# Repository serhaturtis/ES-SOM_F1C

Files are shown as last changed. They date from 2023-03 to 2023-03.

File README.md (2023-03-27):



<br />
<div align="center">
  <a href="https://github.com/serhaturtis/SOM-F1C">
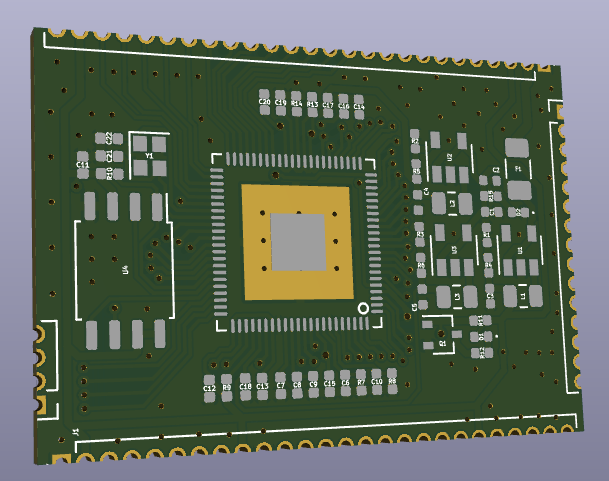
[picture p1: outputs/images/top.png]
    
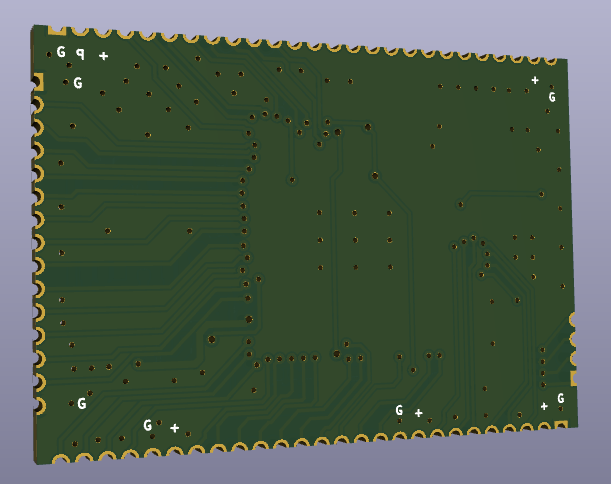
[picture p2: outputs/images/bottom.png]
    
  </a>

<h3 align="center">SOM-F1C</h3>

  <p align="center">
    A System-on-Module With Allwinner F1C Processor 
  </p>
</div>

<!-- WHAT -->
## What?

This is a linux capable system-on-module board made with Allwinner F1C processor. It can hold SPI flash memory (like 16MB NOR or 128MB NAND) on board. 

## Why?

Because I wanted to.

## How?

Headers are placed to the egdes so that manufacturer can recognize it for edge plating.

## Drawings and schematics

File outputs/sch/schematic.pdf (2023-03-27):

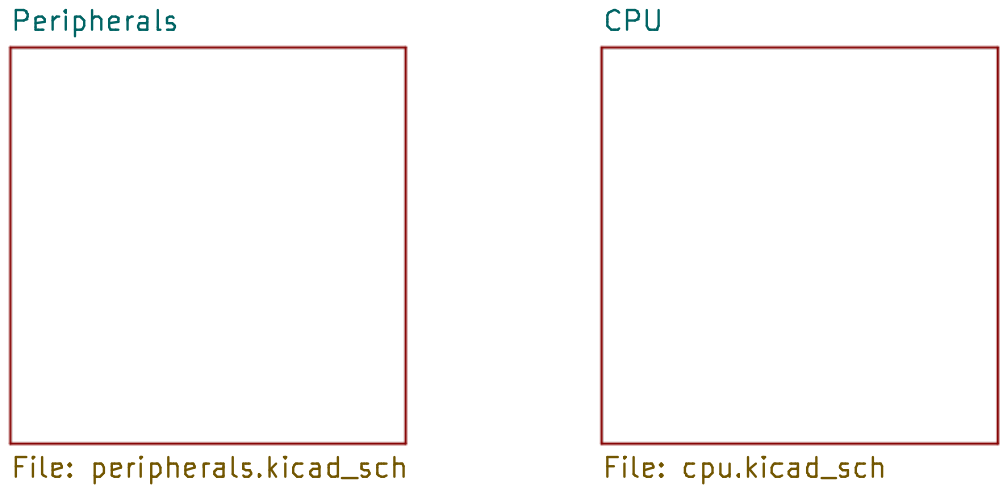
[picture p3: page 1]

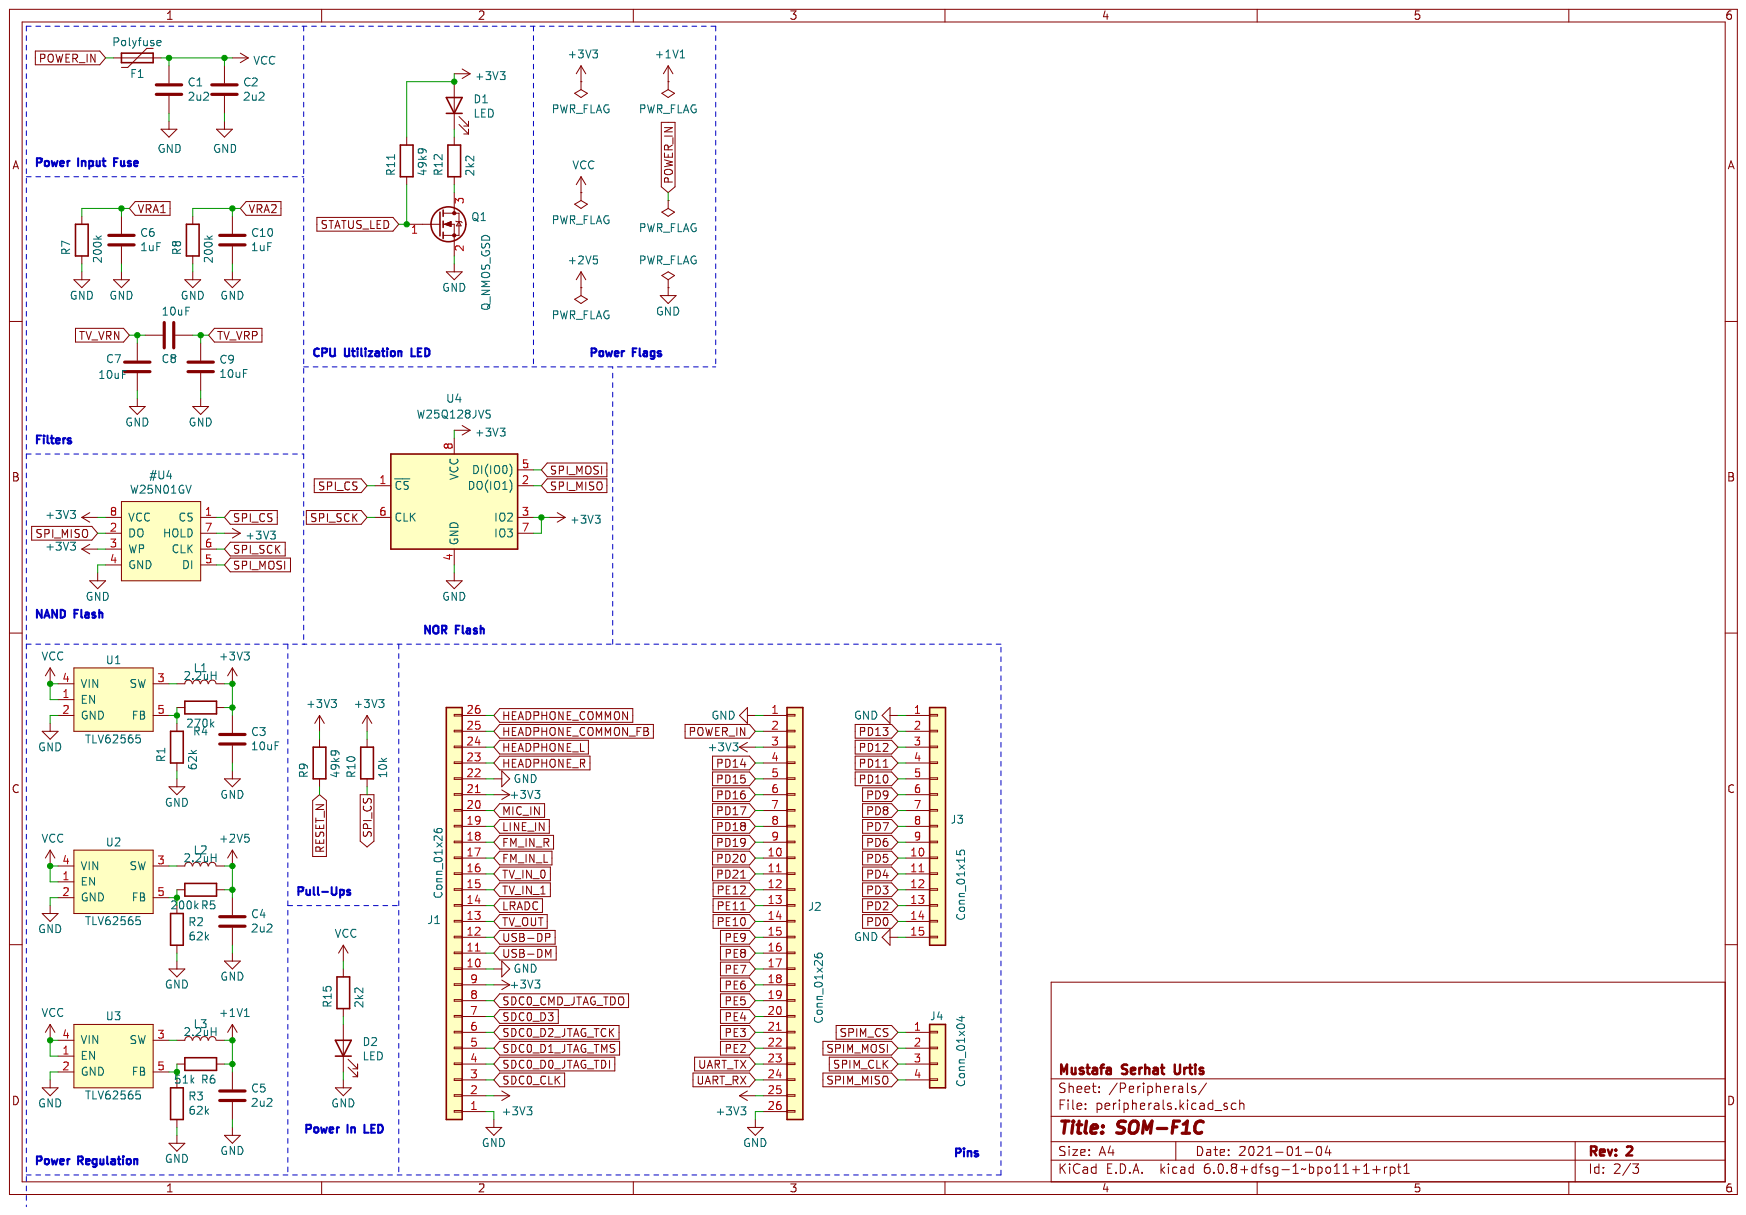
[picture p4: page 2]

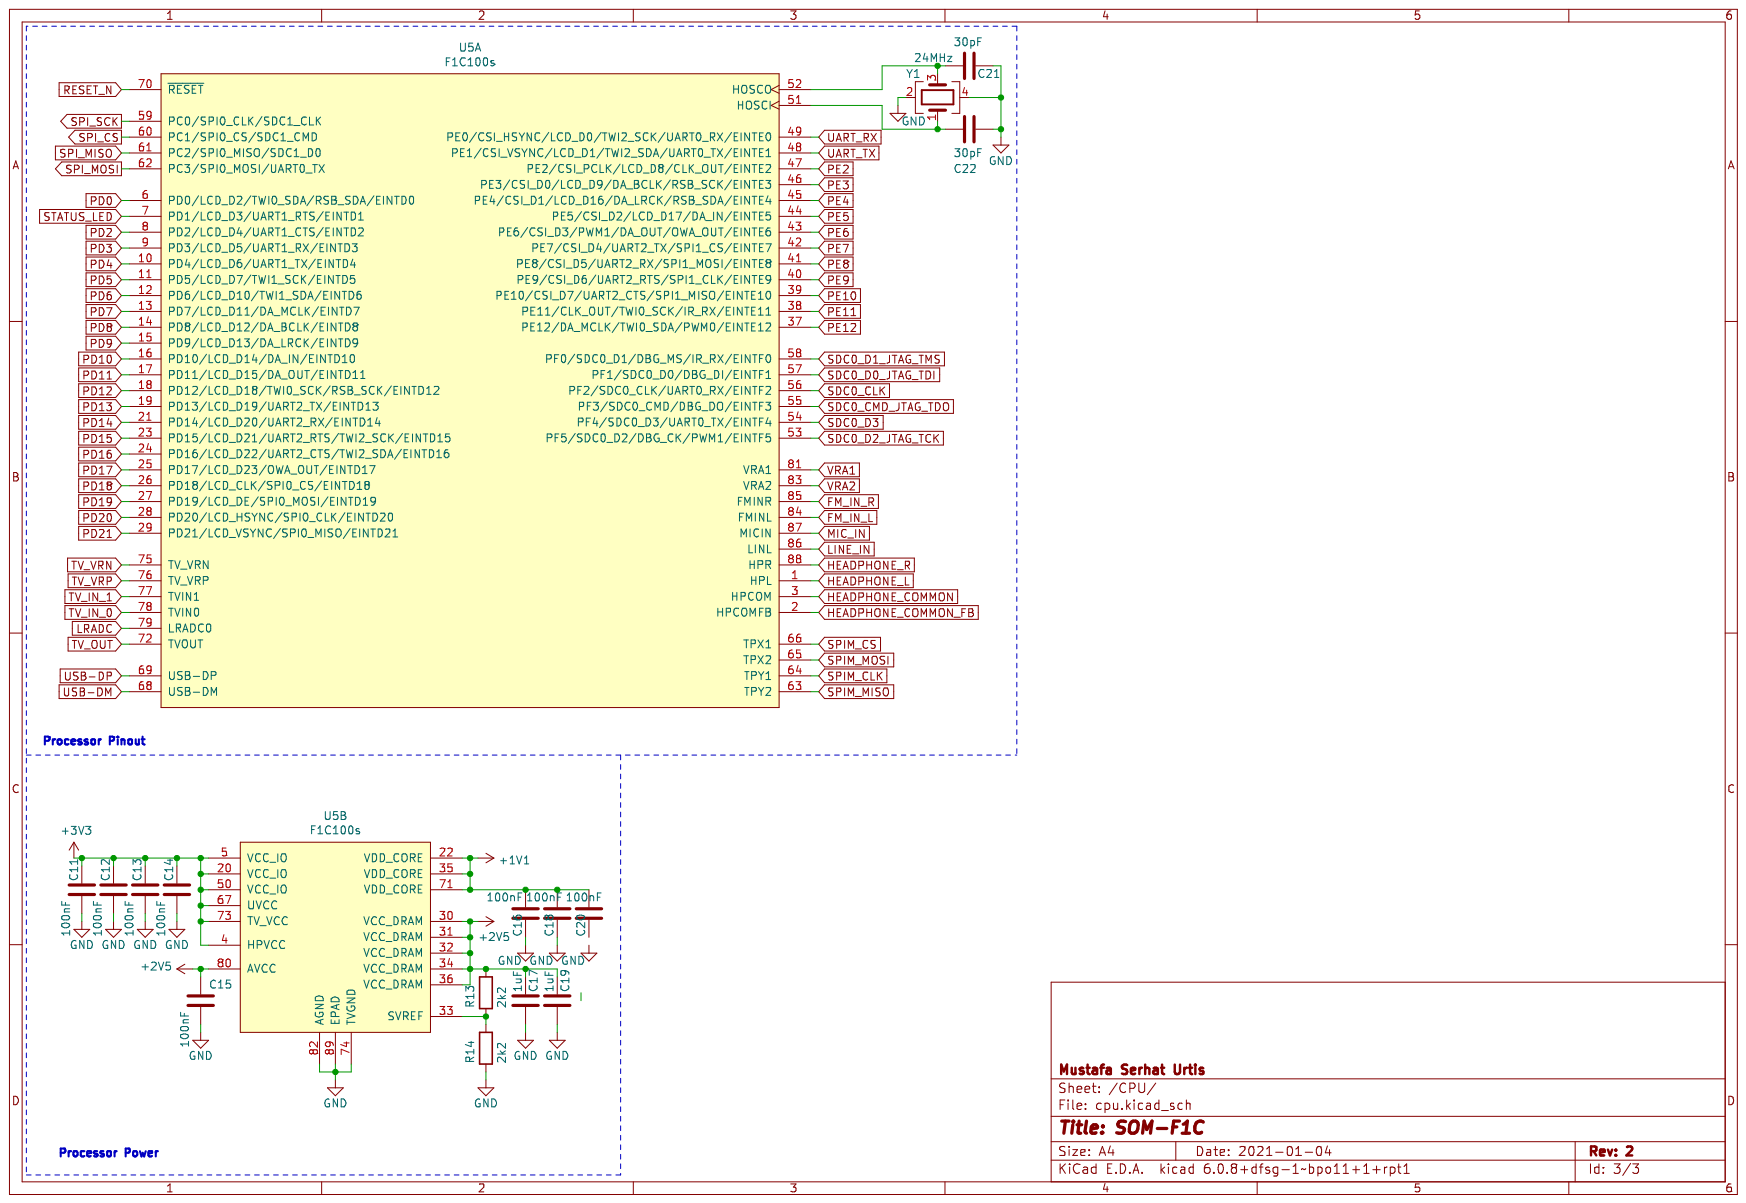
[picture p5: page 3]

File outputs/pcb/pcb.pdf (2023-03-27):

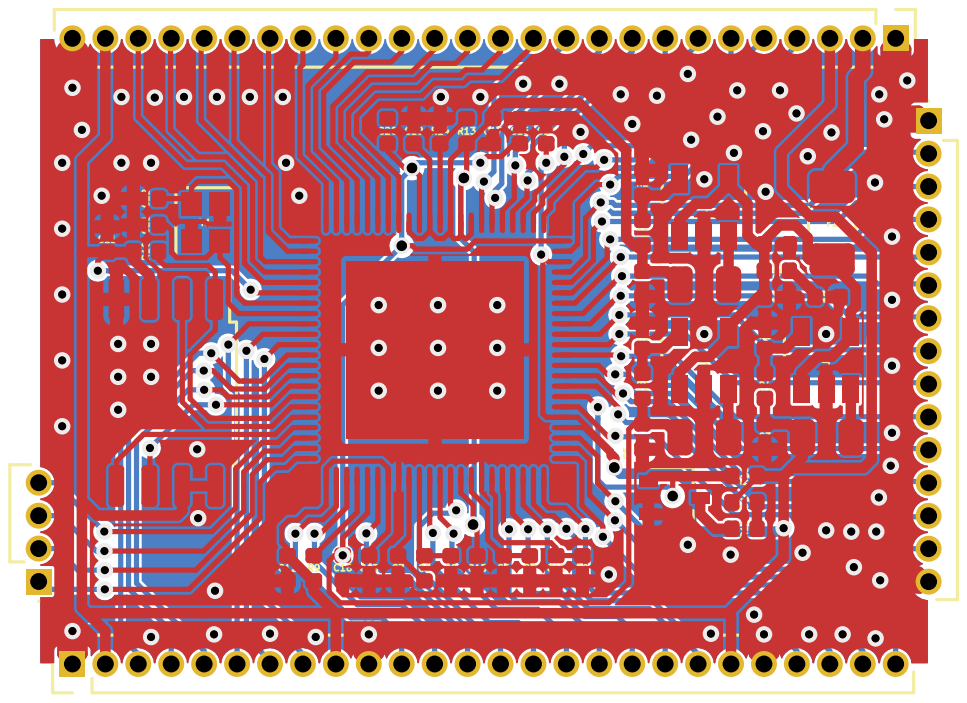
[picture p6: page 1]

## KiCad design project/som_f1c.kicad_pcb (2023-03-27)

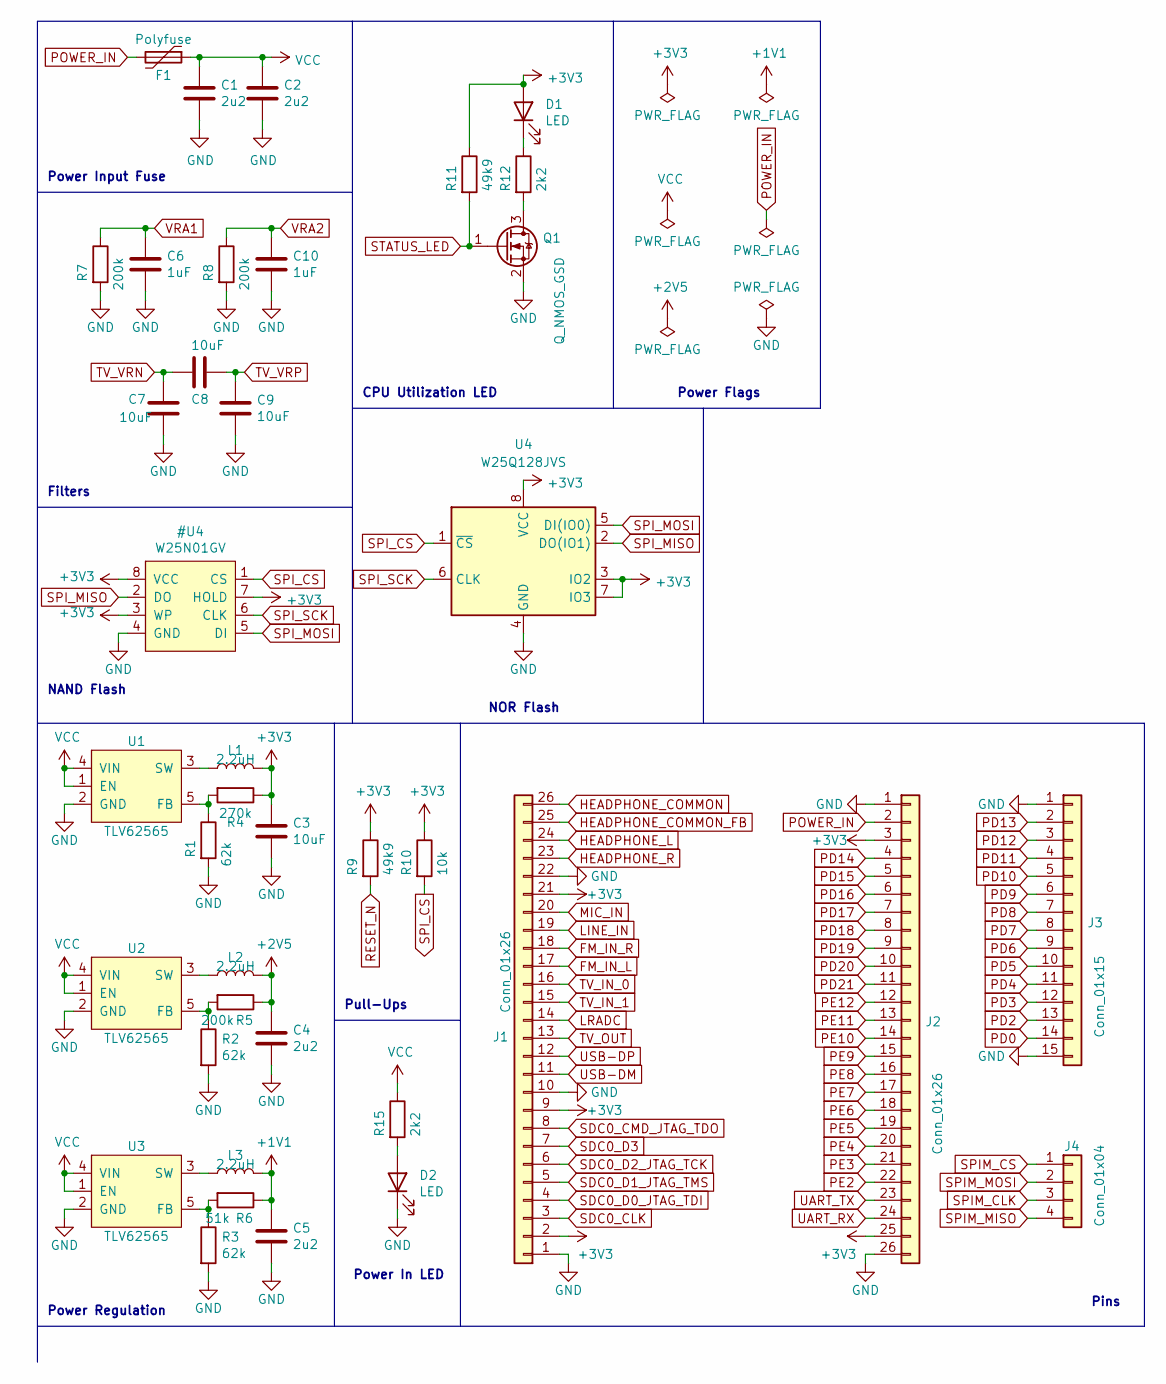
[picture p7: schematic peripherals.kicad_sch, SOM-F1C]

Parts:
C1, C2, C4, C5: 2u2; C_0402_1005Metric
C3, C7, C8, C9: 10uF; C_0402_1005Metric
C6, C10: 1uF; C_0402_1005Metric
D1, D2: LED; LED_0402_1005Metric
F1: Polyfuse; Fuse_1206_3216Metric
J1, J2: Conn_01x26; PinHeader_1x26_P1.27mm_Vertical
J3: Conn_01x15; PinHeader_1x15_P1.27mm_Vertical
J4: Conn_01x04; PinHeader_1x04_P1.27mm_Vertical
L1, L2, L3: 2.2uH; L_0805_2012Metric
Q1: Q_NMOS_GSD; SOT-323_SC-70
R1, R2, R3: 62k; R_0402_1005Metric
R4: 270k; R_0402_1005Metric
R5, R7, R8: 200k; R_0402_1005Metric
R6: 51k; R_0402_1005Metric
R9, R11: 49k9; R_0402_1005Metric
R10: 10k; R_0402_1005Metric
R12, R15: 2k2; R_0402_1005Metric
U1, U2, U3: TLV62565; SOT-23-5
U4: W25Q128JVS; SOIC-8_5.23x5.23mm_P1.27mm

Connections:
+1V1: C5.1, L3.2, R6.1; also elsewhere on the board
+2V5: C4.1, L2.2, R5.1; also elsewhere on the board
FM_IN_L: J1.17; also elsewhere on the board
FM_IN_R: J1.18; also elsewhere on the board
HEADPHONE_COMMON: J1.26; also elsewhere on the board
HEADPHONE_COMMON_FB: J1.25; also elsewhere on the board
HEADPHONE_L: J1.24; also elsewhere on the board
HEADPHONE_R: J1.23; also elsewhere on the board
LINE_IN: J1.19; also elsewhere on the board
LRADC: J1.14; also elsewhere on the board
MIC_IN: J1.20; also elsewhere on the board
unnamed: D1.1 (K), R12.1
unnamed: D2.2 (A), R15.2
unnamed: L1.1, U1.3 (SW)
unnamed: L2.1, U2.3 (SW)
unnamed: L3.1, U3.3 (SW)
unnamed: Q1.3 (D), R12.2
unnamed: R1.1, R4.2, U1.5 (FB)
unnamed: R2.1, R5.2, U2.5 (FB)
unnamed: R3.1, R6.2, U3.5 (FB)
PD0: J3.14; also elsewhere on the board
PD2: J3.13; also elsewhere on the board
PD3: J3.12; also elsewhere on the board
PD4: J3.11; also elsewhere on the board
PD5: J3.10; also elsewhere on the board
PD6: J3.9; also elsewhere on the board
PD7: J3.8; also elsewhere on the board
PD8: J3.7; also elsewhere on the board
PD9: J3.6; also elsewhere on the board
PD10: J3.5; also elsewhere on the board
PD11: J3.4; also elsewhere on the board
PD12: J3.3; also elsewhere on the board
PD13: J3.2; also elsewhere on the board
PD14: J2.4; also elsewhere on the board
PD15: J2.5; also elsewhere on the board
PD16: J2.6; also elsewhere on the board
PD17: J2.7; also elsewhere on the board
PD18: J2.8; also elsewhere on the board
PD19: J2.9; also elsewhere on the board
PD20: J2.10; also elsewhere on the board
PD21: J2.11; also elsewhere on the board
PE2: J2.22; also elsewhere on the board
PE3: J2.21; also elsewhere on the board
PE4: J2.20; also elsewhere on the board
PE5: J2.19; also elsewhere on the board
PE6: J2.18; also elsewhere on the board
PE7: J2.17; also elsewhere on the board
PE8: J2.16; also elsewhere on the board
PE9: J2.15; also elsewhere on the board
PE10: J2.14; also elsewhere on the board
PE11: J2.13; also elsewhere on the board
PE12: J2.12; also elsewhere on the board
POWER_IN: F1.2, J2.2
RESET_N: R9.2; also elsewhere on the board
SDC0_CLK: J1.3; also elsewhere on the board
SDC0_CMD_JTAG_TDO: J1.8; also elsewhere on the board
SDC0_D0_JTAG_TDI: J1.4; also elsewhere on the board
SDC0_D1_JTAG_TMS: J1.5; also elsewhere on the board
SDC0_D2_JTAG_TCK: J1.6; also elsewhere on the board
SDC0_D3: J1.7; also elsewhere on the board
SPIM_CLK: J4.3; also elsewhere on the board
SPIM_CS: J4.1; also elsewhere on the board
SPIM_MISO: J4.4; also elsewhere on the board
SPIM_MOSI: J4.2; also elsewhere on the board
STATUS_LED: Q1.1 (G), R11.2; also elsewhere on the board
TV_IN_0: J1.16; also elsewhere on the board
TV_IN_1: J1.15; also elsewhere on the board
TV_OUT: J1.13; also elsewhere on the board
TV_VRN: C7.1, C8.2; also elsewhere on the board
TV_VRP: C8.1, C9.1; also elsewhere on the board
UART_RX: J2.24; also elsewhere on the board
UART_TX: J2.23; also elsewhere on the board
USB-DM: J1.11; also elsewhere on the board
USB-DP: J1.12; also elsewhere on the board
VCC: C1.1, C2.1, F1.1, R15.1, U1.1 (EN), U1.4 (VIN), U2.1 (EN), U2.4 (VIN), U3.1 (EN), U3.4 (VIN)
VRA1: C6.1, R7.1; also elsewhere on the board
VRA2: C10.1, R8.1; also elsewhere on the board

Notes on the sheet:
NOR Flash
Pull-Ups
CPU Utilization LED
Power Regulation
Power Flags
NAND Flash
Pins
Power Input Fuse
Filters
Power In LED

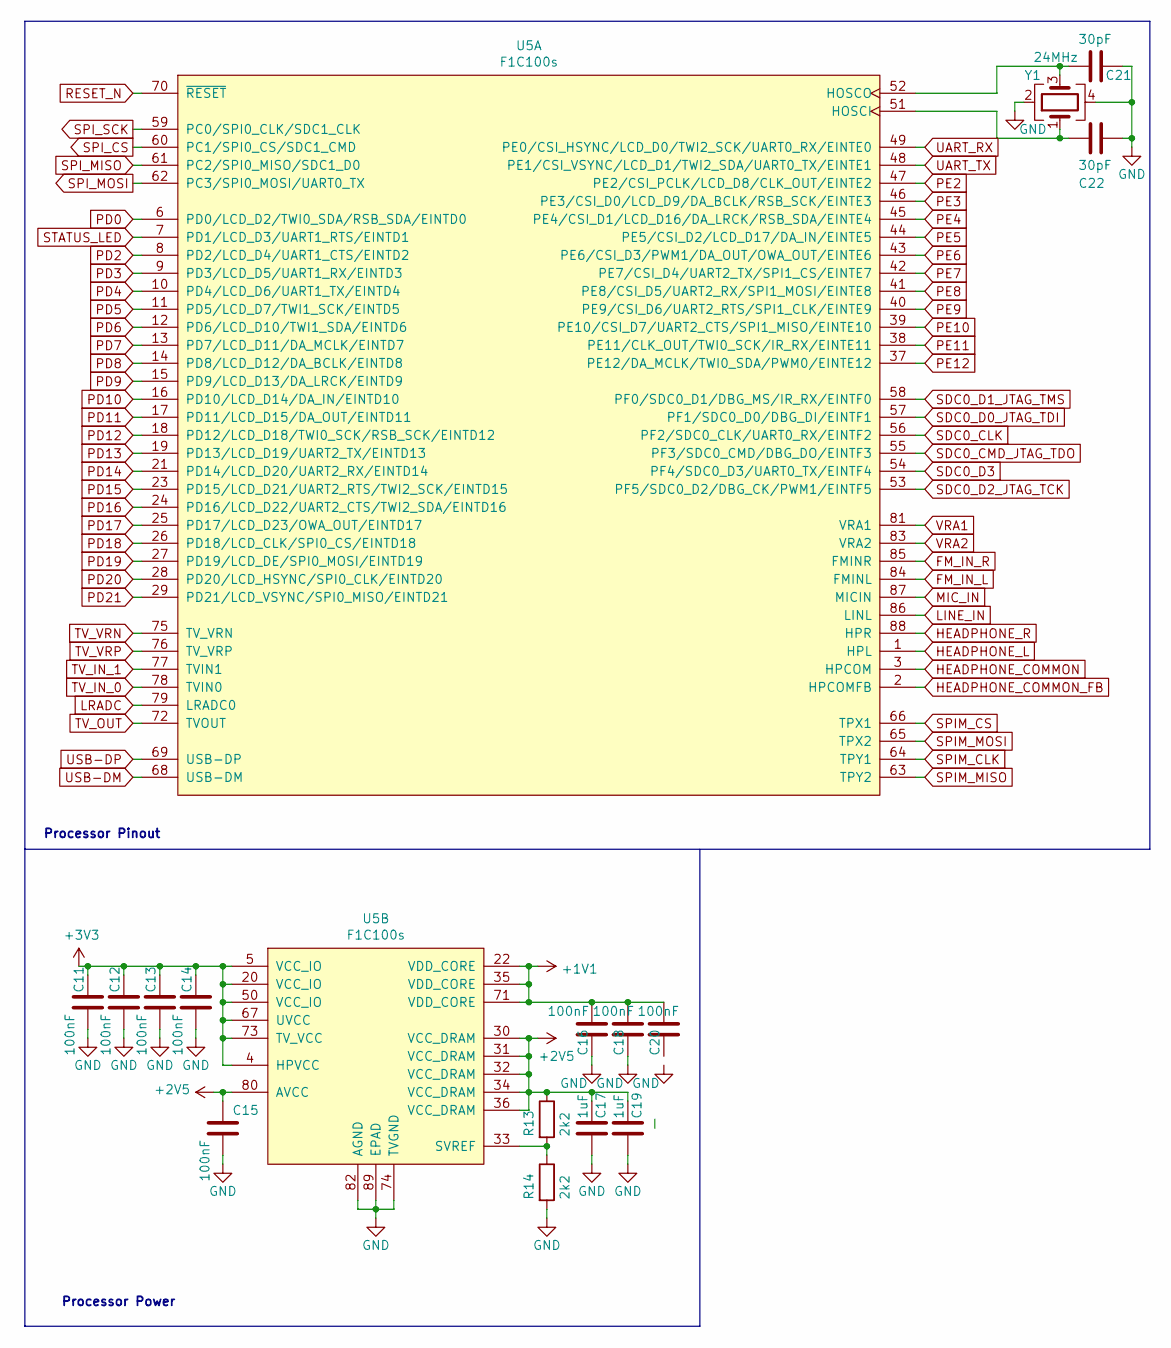
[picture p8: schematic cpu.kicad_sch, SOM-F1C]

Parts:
C11, C12, C13, C14, C15, C16, C18, C20: 100nF; C_0402_1005Metric
C17, C19: 1uF; C_0402_1005Metric
C21, C22: 30pF; C_0402_1005Metric
R13, R14: 2k2; R_0402_1005Metric
U5: F1C100s; QFN-88_EP_10x10_Pitch0.4mm
Y1: 24MHz; Crystal_SMD_2016-4Pin_2.0x1.6mm

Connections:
+1V1: C16.1, C18.1, C20.1, U5.22 (VDD_CORE), U5.35 (VDD_CORE), U5.71 (VDD_CORE); also elsewhere on the board
+2V5: C15.1, C17.1, C19.1, R13.1, U5.30 (VCC_DRAM), U5.31 (VCC_DRAM), U5.32 (VCC_DRAM), U5.34 (VCC_DRAM), U5.36 (VCC_DRAM), U5.80 (AVCC); also elsewhere on the board
FM_IN_L: U5.84 (FMINL); also elsewhere on the board
FM_IN_R: U5.85 (FMINR); also elsewhere on the board
HEADPHONE_COMMON: U5.3 (HPCOM); also elsewhere on the board
HEADPHONE_COMMON_FB: U5.2 (HPCOMFB); also elsewhere on the board
HEADPHONE_L: U5.1 (HPL); also elsewhere on the board
HEADPHONE_R: U5.88 (HPR); also elsewhere on the board
LINE_IN: U5.86 (LINL); also elsewhere on the board
LRADC: U5.79 (LRADC0); also elsewhere on the board
MIC_IN: U5.87 (MICIN); also elsewhere on the board
unnamed: C21.2, U5.52 (HOSCO), Y1.3
unnamed: C22.2, U5.51 (HOSCI), Y1.1
unnamed: R13.2, R14.1, U5.33 (SVREF)
PD0: U5.6 (PD0/LCD_D2/TWI0_SDA/RSB_SDA/EINTD0); also elsewhere on the board
PD2: U5.8 (PD2/LCD_D4/UART1_CTS/EINTD2); also elsewhere on the board
PD3: U5.9 (PD3/LCD_D5/UART1_RX/EINTD3); also elsewhere on the board
PD4: U5.10 (PD4/LCD_D6/UART1_TX/EINTD4); also elsewhere on the board
PD5: U5.11 (PD5/LCD_D7/TWI1_SCK/EINTD5); also elsewhere on the board
PD6: U5.12 (PD6/LCD_D10/TWI1_SDA/EINTD6); also elsewhere on the board
PD7: U5.13 (PD7/LCD_D11/DA_MCLK/EINTD7); also elsewhere on the board
PD8: U5.14 (PD8/LCD_D12/DA_BCLK/EINTD8); also elsewhere on the board
PD9: U5.15 (PD9/LCD_D13/DA_LRCK/EINTD9); also elsewhere on the board
PD10: U5.16 (PD10/LCD_D14/DA_IN/EINTD10); also elsewhere on the board
PD11: U5.17 (PD11/LCD_D15/DA_OUT/EINTD11); also elsewhere on the board
PD12: U5.18 (PD12/LCD_D18/TWI0_SCK/RSB_SCK/EINTD12); also elsewhere on the board
PD13: U5.19 (PD13/LCD_D19/UART2_TX/EINTD13); also elsewhere on the board
PD14: U5.21 (PD14/LCD_D20/UART2_RX/EINTD14); also elsewhere on the board
PD15: U5.23 (PD15/LCD_D21/UART2_RTS/TWI2_SCK/EINTD15); also elsewhere on the board
PD16: U5.24 (PD16/LCD_D22/UART2_CTS/TWI2_SDA/EINTD16); also elsewhere on the board
PD17: U5.25 (PD17/LCD_D23/OWA_OUT/EINTD17); also elsewhere on the board
PD18: U5.26 (PD18/LCD_CLK/SPI0_CS/EINTD18); also elsewhere on the board
PD19: U5.27 (PD19/LCD_DE/SPI0_MOSI/EINTD19); also elsewhere on the board
PD20: U5.28 (PD20/LCD_HSYNC/SPI0_CLK/EINTD20); also elsewhere on the board
PD21: U5.29 (PD21/LCD_VSYNC/SPI0_MISO/EINTD21); also elsewhere on the board
PE2: U5.47 (PE2/CSI_PCLK/LCD_D8/CLK_OUT/EINTE2); also elsewhere on the board
PE3: U5.46 (PE3/CSI_D0/LCD_D9/DA_BCLK/RSB_SCK/EINTE3); also elsewhere on the board
PE4: U5.45 (PE4/CSI_D1/LCD_D16/DA_LRCK/RSB_SDA/EINT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); also elsewhere on the board
PE5: U5.44 (PE5/CSI_D2/LCD_D17/DA_IN/EINTE5); also elsewhere on the board
PE6: U5.43 (PE6/CSI_D3/PWM1/DA_OUT/OWA_OUT/EINTE6); also elsewhere on the board
PE7: U5.42 (PE7/CSI_D4/UART2_TX/SPI1_CS/EINTE7); also elsewhere on the board
PE8: U5.41 (PE8/CSI_D5/UART2_RX/SPI1_MOSI/EINTE8); also elsewhere on the board
PE9: U5.40 (PE9/CSI_D6/UART2_RTS/SPI1_CLK/EINTE9); also elsewhere on the board
PE10: U5.39 (PE10/CSI_D7/UART2_CTS/SPI1_MISO/EINTE10); also elsewhere on the board
PE11: U5.38 (PE11/CLK_OUT/TWI0_SCK/IR_RX/EINTE11); also elsewhere on the board
PE12: U5.37 (PE12/DA_MCLK/TWI0_SDA/PWM0/EINTE12); also elsewhere on the board
RESET_N: U5.70 (~RESET); also elsewhere on the board
SDC0_CLK: U5.56 (PF2/SDC0_CLK/UART0_RX/EINTF2); also elsewhere on the board
SDC0_CMD_JTAG_TDO: U5.55 (PF3/SDC0_CMD/DBG_DO/EINTF3); also elsewhere on the board
SDC0_D0_JTAG_TDI: U5.57 (PF1/SDC0_D0/DBG_DI/EINTF1); also elsewhere on the board
SDC0_D1_JTAG_TMS: U5.58 (PF0/SDC0_D1/DBG_MS/IR_RX/EINTF0); also elsewhere on the board
SDC0_D2_JTAG_TCK: U5.53 (PF5/SDC0_D2/DBG_CK/PWM1/EINTF5); also elsewhere on the board
SDC0_D3: U5.54 (PF4/SDC0_D3/UART0_TX/EINTF4); also elsewhere on the board
SPIM_CLK: U5.64 (TPY1); also elsewhere on the board
SPIM_CS: U5.66 (TPX1); also elsewhere on the board
SPIM_MISO: U5.63 (TPY2); also elsewhere on the board
SPIM_MOSI: U5.65 (TPX2); also elsewhere on the board
STATUS_LED: U5.7 (PD1/LCD_D3/UART1_RTS/EINTD1); also elsewhere on the board
TV_IN_0: U5.78 (TVIN0); also elsewhere on the board
TV_IN_1: U5.77 (TVIN1); also elsewhere on the board
TV_OUT: U5.72 (TVOUT); also elsewhere on the board
TV_VRN: U5.75 (TV_VRN); also elsewhere on the board
TV_VRP: U5.76 (TV_VRP); also elsewhere on the board
UART_RX: U5.49 (PE0/CSI_HSYNC/LCD_D0/TWI2_SCK/UART0_RX/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); also elsewhere on the board
UART_TX: U5.48 (PE1/CSI_VSYNC/LCD_D1/TWI2_SDA/UART0_TX/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); also elsewhere on the board
USB-DM: U5.68 (USB-DM); also elsewhere on the board
USB-DP: U5.69 (USB-DP); also elsewhere on the board
VRA1: U5.81 (VRA1); also elsewhere on the board
VRA2: U5.83 (VRA2); also elsewhere on the board

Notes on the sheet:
Processor Power
Processor Pinout

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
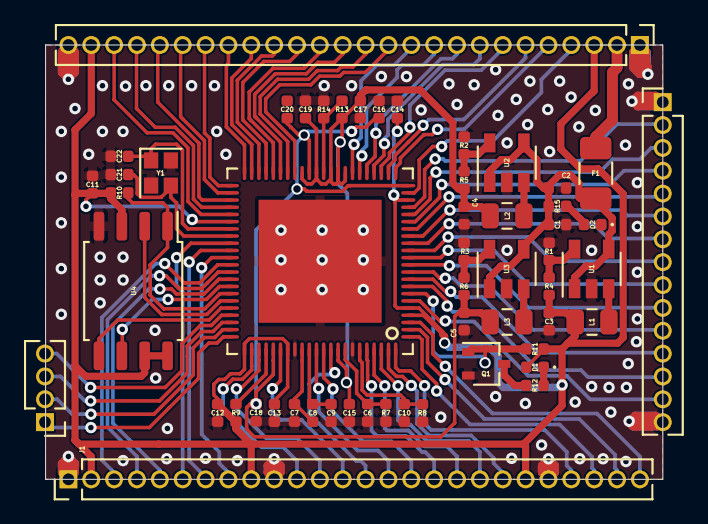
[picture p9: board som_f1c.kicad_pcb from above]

Board: 2 copper layers, 34.3 x 24.1 mm, 54 parts (0 on the bottom side), 86 nets.

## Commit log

2022-01-09 Initial commit.
    [cpu.sch, peripherals.sch, power.sch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]
2023-01-08 updated to version 6.x
    [cpu.kicad_sch, cpu.sch, peripherals.kicad_sch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]
2023-01-08 fixed some drc errors, added module footprint and symbol library
    [som_f1c.kicad_pcb]
2023-03-27 added extra spi pins
    [cpu.kicad_sch, peripherals.kicad_sch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]
